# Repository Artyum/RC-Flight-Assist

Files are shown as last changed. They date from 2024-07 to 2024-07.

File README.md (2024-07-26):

# RC Flight Assist (RCFA) Telemetry System

RCFA is a telemetry system for RC pilots, designed specifically for outdoor pattern flying, such as F3A or F3M classes. The system provides better control over the airplane during acrobatics by implementing a radio telemetry mechanism that accurately indicates the position within the flight area. With RCFA, pilots can maintain the proper position in the sky, resulting in better handling and improved skills. The system was tested in collaboration with the top Polish F3A pilot of 2015.

#### How Does It Work?

The RCFA system comprises two separate electronic devices: the Transmitter and the Receiver. The primary role of the Transmitter is to get the 3D or 2D position from GPS and altimeter sensors and send the data to the pilot’s Receiver. The Receiver converts the signal into sound patterns, which the pilot can hear through the built-in speaker or headphones to receive telemetry information.

The basic usage of the RCFA involves defining two points on the ground to determine the flight area. The first point (P1) is the pilot’s position, where the airplane will be controlled from. The second point (P2) is the direction to the flight line where the airplane shall be controlled. These points can be set by walking with the RCFA to the desired positions on the airfield or by writing the coordinates in the configuration file (rcfa.ini). The optimal distance between P1 and P2 depends on GPS signal strength and usually does not need to be more than 20m.

#### Setting Up the Flight Area

Once points P1 and P2 are set within the Transmitter, the RCFA system automatically calculates the remaining flight area coordinates based on preset options: the ideal Flight Line (marked with points A, B, and C), the Green Zone (green color), and the Flight Area (blue color). The pilot’s job is to keep the airplane between the green rectangles.

During a flight, the RCFA Receiver generates tones that change according to the airplane’s distance from the Green Zone. This allows the pilot to react quickly and steer the airplane to the desired position in the sky. The pilot will know exactly how far the airplane is from the flight line, and whether it is ahead or behind the Green Zone, too high, or too far to the left or right side of the Flight Area.

#### Post-Flight Scoring

When the flight is over, the system calculates a score based on the time spent in the zone and overall flight time. This score is automatically stored in a KML file. The logger file can be opened instantly in Google Earth (Windows or Linux) to examine the flight and check the scoring.

#### Additional Features of the RCFA

**GPS Logger**: The system is highly customizable. Users can change various parameters such as the distance from the pilot to the flight line, area angle, flight plane width, and more (nearly 30 options). It has an integrated MicroSD slot for a memory card, which is used to store and read area parameters and to write position data as a high-accuracy GPS Logger. The system implements unique filter algorithms, ensuring high accuracy in the GPS data stream and altitude measurements. The RCFA also allows the use of a barometer for even more accurate altitude measurement. The Logger writes data directly in KML format, which can be instantly opened in Google Earth.

**Real-Time Tracking**: The RCFA can stream data to the Receiver about current 3D coordinates through the RX/TX interface (USB2TTL). The data stream (longitude, latitude, and altitude) can be read and visualized on a PC in real-time. Depending on barometer availability, the altitude data can be taken from GPS or barometer. Users can choose either absolute (mean sea level) or relative (to the pilot’s position) altitude readings.

**Variometer**: The RCFA includes a variometer feature, which can be used in gliders and other types of RC airplanes. The variometer can use GPS data or a barometer to indicate altitude changes. The data is sent to the Receiver, allowing the pilot to control descending or ascending in real-time.

# Overview
https://www.youtube.com/watch?v=m0nCrscLPIs

#### RC Flight Assist - Real-time tracking demo
https://www.youtube.com/watch?v=_wvuzFEu3uk

## Full Features List

The list of configurable parameters:
* Distance in meters between the Pilot and the Flight Line
* Area angle in degrees
* Flight Area width
* Flight line width
* Flight Area boundary alarm (Out-Of-Area)
* Altitude alarm
* Set points P1 and P2 manually
* Automatic Flight Area lock
* Real-time tracking
* Automatic reference altitude
* Manual setting of reference altitude
* GPS sample rate in 'Reads Per Second'
* GPS Logger Automatic mode
* GPS Logger Manual mode (free flight)
* Logger speed frequency
* Four different modes of Floor option
* "Low accuracy" information feature
* Configurable filtering algorithm for GPS, Altimeter, and Variometer
* Radio module switch
* Altimeter switch
* Variometer mode
* (Variometer) Minimum vertical speed ratio
* (Variometer) Maximum vertical speed ratio
* Time zone relative to UTC
* Initial sound volume in the Receiver
* Event log

### GPS Logger

RC Flight Assist can be used as a GPS Logger. The data is stored on a Micro SD card in KML format, which can be opened directly in Google Earth. The flight path is visualized as a line in 3D space as an animated track. The logger is controlled by several options:

1. **Stream Speed Frequency**: The coordinates can be saved every 0.5 to 60 seconds.
2. **GPS Data Acquiring Speed**: The data can be acquired 1, 5, or 10 times per second.
3. **Reference Altitude**: You can manually set the accurate reference altitude to ensure the plot is at the exact height. The altitude measurement relies on the high-accuracy barometer sensor MPL3115A2. If the barometer is not used, the altitude data is acquired from GPS.

The Logger can work in two modes:

**Automatic Mode**: Designed for acrobatic flights, so the pilot does not have to remember to enable or disable the Logger before each flight. The logger will start when the airplane flies into the flight zone and stop when leaving it.

**Manual Mode**: Along with the attached barometer, this makes RCFA a high-quality GPS Logger. In this mode, the Logger must be enabled and disabled manually by pressing the relevant buttons on the transmitter. To reduce energy drain, the radio module can be turned off.

### Real-time Tracking

The RC Flight Assist (RCFA) system is capable of sending position data to the Receiver in real-time. This data stream can be visualized on a PC directly in Google Earth. Currently, Google Earth has limited capabilities for displaying altitude in real-time mode. However, several third-party applications, such as GooPs (goopstechnologies.com) or EarthBridge (mboffin.com/earthbridge), can work as extensions to Google Earth to enhance its real-time tracking capabilities.

### Technical Details

**Radio Frequency**: 433MHz, 868MHz, 915MHz  
**Frequency-Hopping Spread Spectrum (FHSS)**  
**Range**: 700+/-100m (tested in open air with copper wire antenna)  
**Input Voltage**: 7-12V (2S/3S LiPo)  
**GPS Compatibility**: Global Top (MT3318, MT3329, MT3339), u-Blox (M7, M8)

#### Receiver (RX)
* **Headphones**: 3.5mm jack port
* **Average Current**: 50mA
* **Size**: 51 x 38mm
* **Weight**: ~17g

#### Transmitter (TX)
* **MicroSD Card**: 256MB-32GB class 4 (FAT32)
* **Maximum Transmit Power**: 20dB (100mW)
* **Average Current**: 150mA
* **Size**: 52 x 40mm

### Variometer

The RCFA Telemetry System can function as a variometer, providing real-time altitude data sourced from the GPS module or barometer (if available). Barometric altitude readings generally offer higher quality, but certain GPS modules such as u-Blox M8 or M7 series can also provide excellent 3D positioning signals. This telemetry system enables pilots to control ascents and descents in real-time from the ground. Specific sound patterns emitted by the receiver indicate altitude changes.

#### Customization Options

The variometer mode is highly customizable:
- **Low Pass**: Defines the minimum altitude change considered as horizontal flight.
- **High Pass**: Sets the altitude change threshold that triggers sound gradation in the speaker.

This flexibility allows pilots to tailor the variometer's responsiveness to their specific flying needs and preferences.

## RC Flight Assist (RCFA) Kit Components

#### 1. Transmitter
- **Description**: The transmitter module of the RCFA system is responsible for sending the aircraft's position data to the receiver. It gathers data from the GPS and altimeter sensors, then transmits this information using a specified radio frequency.
- **Key Features**:
  - Frequency-hopping spread spectrum (FHSS) support
  - Compatible with multiple GPS modules
  - Configurable transmission power
 
RCFA_TX

#### 2. Receiver
- **Description**: The receiver module receives position data from the transmitter and converts it into audible signals for the pilot. It helps in maintaining the aircraft within the designated flight area by providing real-time feedback.
- **Key Features**:
  - Headphone jack for audio feedback
  - Real-time tracking capability
  - Configurable sound patterns for various flight conditions
 
RCFA_RX

#### 3. GPS
- **Description**: The GPS module provides the necessary positional data for the RCFA system. It can determine the 2D or 3D position of the aircraft and relay this information to the transmitter.
- **Key Features**:
  - High compatibility (Global Top MT3318, MT3329, MT3339, u-Blox M7, M8 series)
  - Supports logging of satellite data
  - Provides accurate altitude data with the option to use a barometer for enhanced accuracy

#### 4. UART USB
- **Description**: The UART USB interface is used for configuring the RCFA system and for data logging purposes. It allows for easy communication between the RCFA modules and a PC for setup and data transfer.
- **Key Features**:
  - Enables configuration of system parameters via `rcfa.ini`
  - Facilitates firmware updates and debugging
  - Supports real-time data visualization on a PC using compatible software like Google Earth

IMG_20160701_214035_HDR

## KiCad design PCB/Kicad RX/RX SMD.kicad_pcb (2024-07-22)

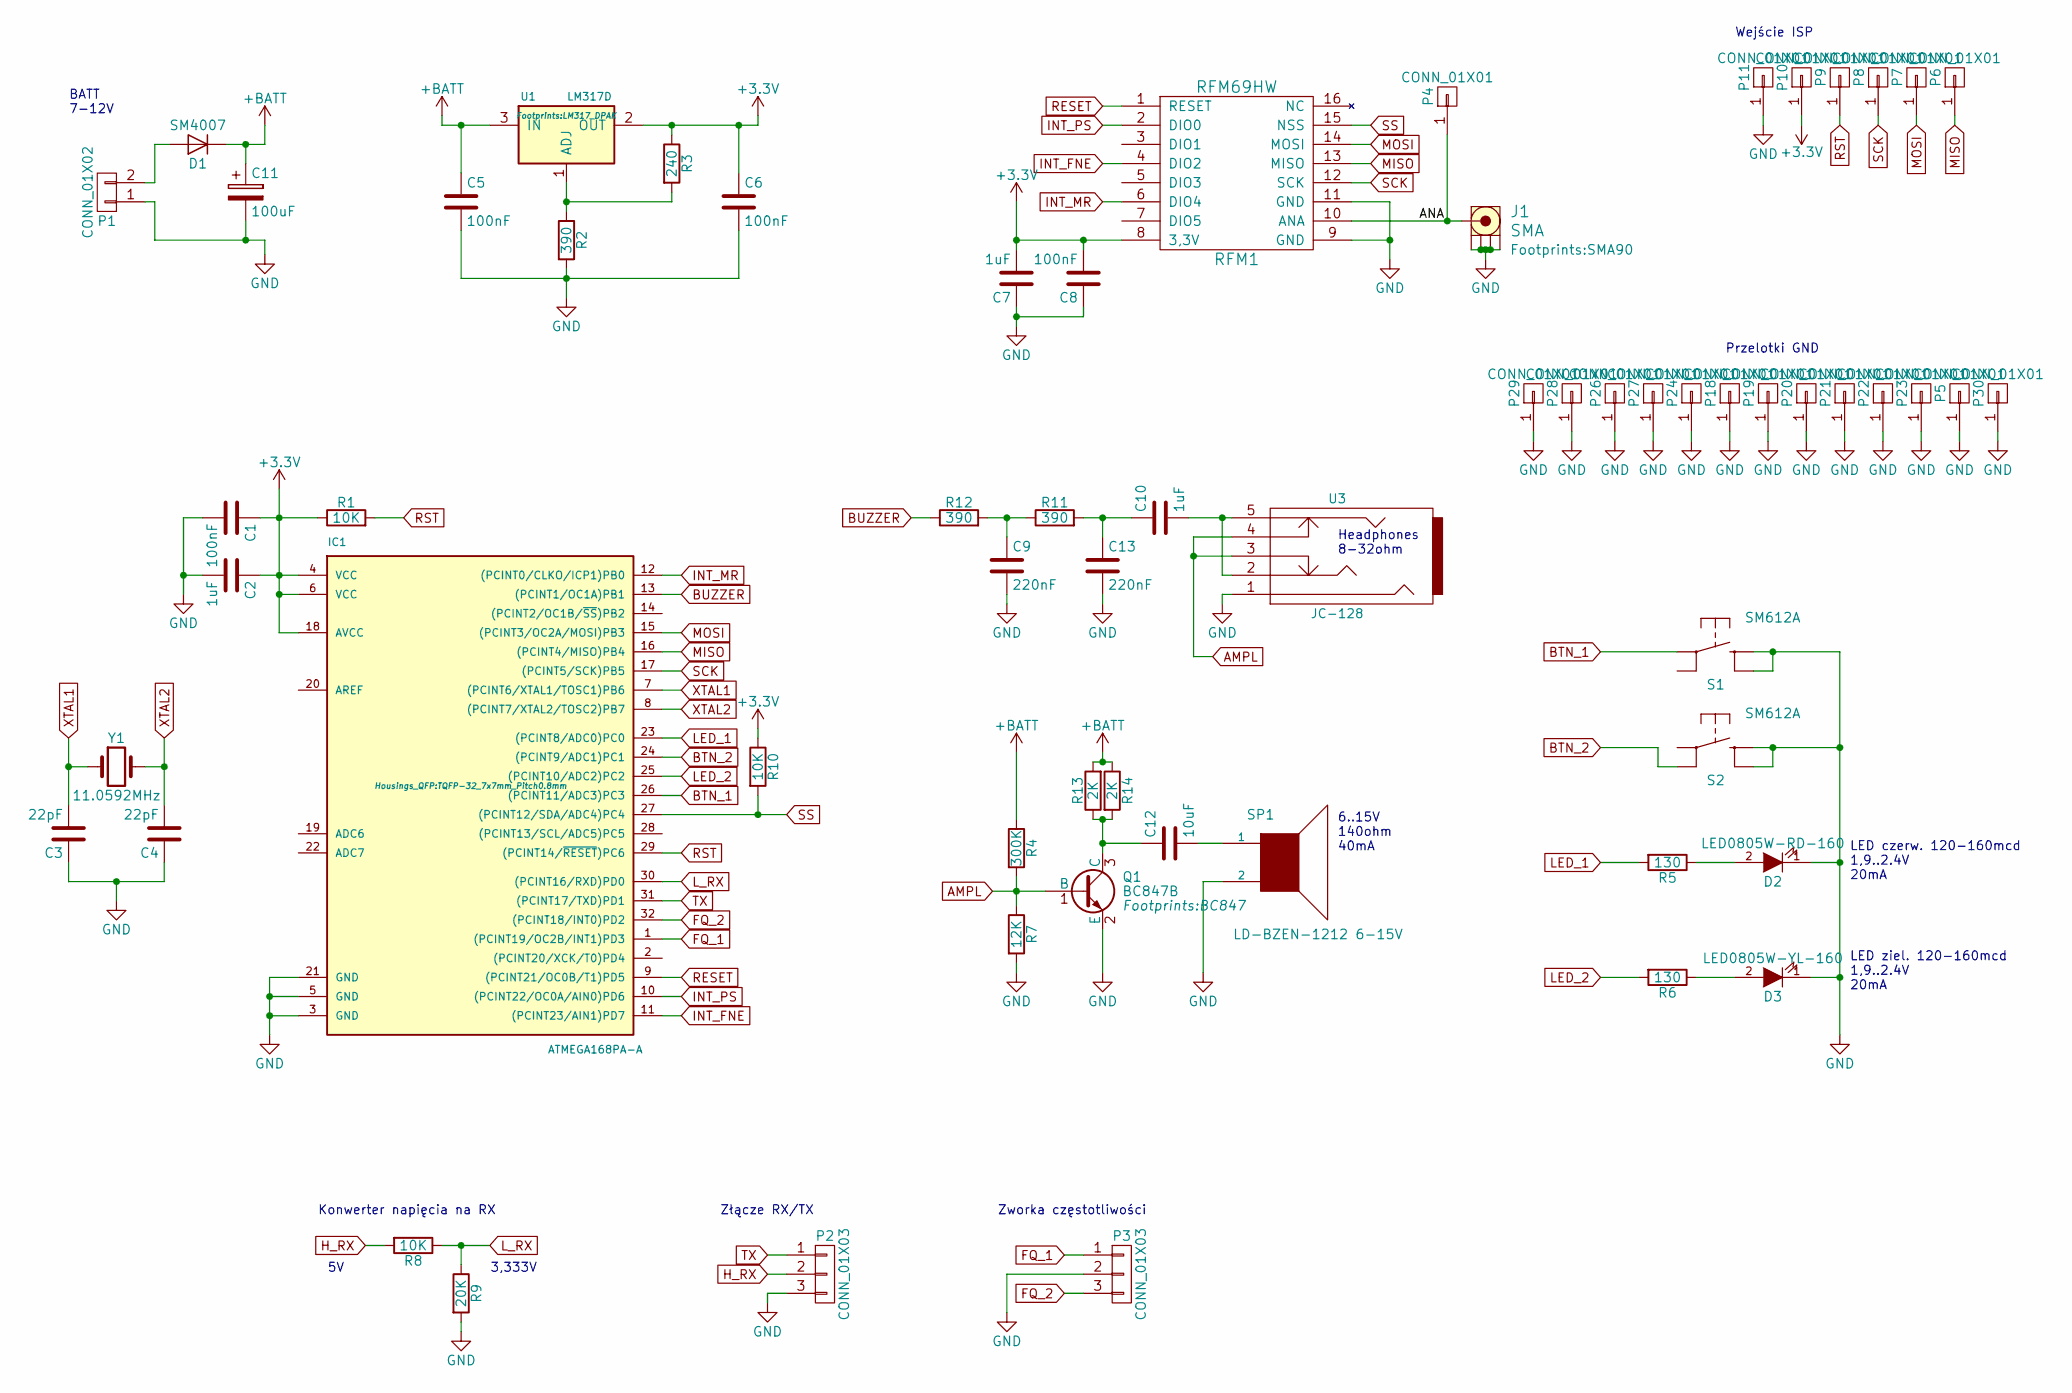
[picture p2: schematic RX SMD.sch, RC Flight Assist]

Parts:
C1, C5, C6, C8: 100nF; C_0805
C2, C7, C10: 1uF; C_0805
C3, C4: 22pF; C_0805
C9, C13: 220nF; C_0805
C11: 100uF; c_elec_6.3x5.3
C12: 10uF; C_0805
D1: SM4007; MELF_Standard
D2: LED0805W-RD-160; LED_0805
D3: LED0805W-YL-160; LED_0805
IC1: ATMEGA168PA-A; TQFP-32_7x7mm_Pitch0.8mm
J1: SMA; SMA90
P1: CONN_01X02; Pin_Header_Angled_1x02
P2, P3: CONN_01X03; Pin_Header_Angled_1x03
P4, P5, P6, P7, P8, P9, P10, P11, P18, P19, P20, P21, P22, P23, P24, P26, P27, P28, P29, P30: CONN_01X01; 1Pin
Q1: BC847B; BC847
R1, R8, R10: 10K; R_0805
R2, R11, R12: 390; R_0805
R3: 240; R_0805
R4: 300K; R_0805
R5, R6: 130; R_0805
R7: 12K; R_0805
R9: 20K; R_0805
R13, R14: 2K; R_0805
RFM1: RFM69HW; RFM69HW_SMD
S1, S2: SM612A; B3F_10XX
SP1: LD-BZEN-1212 6-15V; BUZZER_12x6.5
U1: LM317D; LM317_DPAK
U3: JC-128
Y1: 11.0592MHz; Crystal_HC49-U_Vertical

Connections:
+3V3: C1.1, C2.1, C6.1, C7.2, C8.2, IC1.4 (VCC), IC1.6 (VCC), IC1.18 (AVCC), P10.1, R1.1, R3.1, R10.1, RFM1.8 (3,3V), U1.2 (OUT)
+BATT: C5.1, C11.1, D1.1 (K), R4.1, R13.2, R14.1, U1.3 (IN)
/ANA: J1.1 (RF), P4.1, RFM1.10 (ANA)
AMPL: Q1.1 (B), R4.2, R7.1, U3.3, U3.4
BTN_1: IC1.26 ((PCINT11/ADC3)PC3), S1.3
BTN_2: IC1.24 ((PCINT9/ADC1)PC1), S2.4 (P1)
BUZZER: IC1.13 ((PCINT1/OC1A)PB1), R12.1
FQ_1: IC1.1 ((PCINT19/OC2B/INT1)PD3), P3.1
FQ_2: IC1.32 ((PCINT18/INT0)PD2), P3.3
GND: C1.2, C2.2, C3.1, C4.1, C5.2, C6.2, C7.1, C8.1, C9.2, C11.2, C13.2, D2.1 (K), D3.1 (K), IC1.3 (GND), IC1.5 (GND), IC1.21 (GND), J1.2 (GND1), J1.3 (GND2), J1.4 (GND3), J1.5 (GND4), P1.1, P2.3, P3.2, P5.1, P11.1, P18.1, P19.1, P20.1, P21.1, P22.1, P23.1, P24.1, P26.1, P27.1, P28.1, P29.1, P30.1, Q1.2 (E), R2.2, R7.2, R9.2, RFM1.9 (GND), RFM1.11 (GND), S1.1 (S), S1.2 (S1), S2.1 (S), S2.2 (S1), SP1.2, U3.1
H_RX: P2.2, R8.2
INT_FNE: IC1.11 ((PCINT23/AIN1)PD7), RFM1.4 (DIO2)
INT_MR: IC1.12 ((PCINT0/CLKO/ICP1)PB0), RFM1.6 (DIO4)
INT_PS: IC1.10 ((PCINT22/OC0A/AIN0)PD6), RFM1.2 (DIO0)
LED_1: IC1.23 ((PCINT8/ADC0)PC0), R5.2
LED_2: IC1.25 ((PCINT10/ADC2)PC2), R6.2
L_RX: IC1.30 ((PCINT16/RXD)PD0), R8.1, R9.1
MISO: IC1.16 ((PCINT4/MISO)PB4), P6.1, RFM1.13 (MISO)
MOSI: IC1.15 ((PCINT3/OC2A/MOSI)PB3), P7.1, RFM1.14 (MOSI)
unnamed: C9.1, R11.1, R12.2
unnamed: C10.1, C13.1, R11.2
unnamed: C10.2, U3.2, U3.5
unnamed: C12.1, Q1.3 (C), R13.1, R14.2
unnamed: C12.2, SP1.1
unnamed: D1.2 (A), P1.2
unnamed: D2.2 (A), R5.1
unnamed: D3.2 (A), R6.1
unnamed: R2.1, R3.2, U1.1 (ADJ)
RESET: IC1.9 ((PCINT21/OC0B/T1)PD5), RFM1.1 (RESET)
RST: IC1.29 ((PCINT14/~RESET~)PC6), P9.1, R1.2
SCK: IC1.17 ((PCINT5/SCK)PB5), P8.1, RFM1.12 (SCK)
SS: IC1.27 ((PCINT12/SDA/ADC4)PC4), R10.2, RFM1.15 (NSS)
TX: IC1.31 ((PCINT17/TXD)PD1), P2.1
XTAL1: C3.2, IC1.7 ((PCINT6/XTAL1/TOSC1)PB6), Y1.1
XTAL2: C4.2, IC1.8 ((PCINT7/XTAL2/TOSC2)PB7), Y1.2

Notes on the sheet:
LED czerw. 120-160mcd 1,9..2.4V 20mA
LED ziel. 120-160mcd 1,9..2.4V 20mA
Złącze RX/TX
Zworka częstotliwości
Konwerter napięcia na RX
BATT 7-12V
6..15V 140ohm 40mA
Headphones 8-32ohm
Wejście ISP
3,333V
Przelotki GND

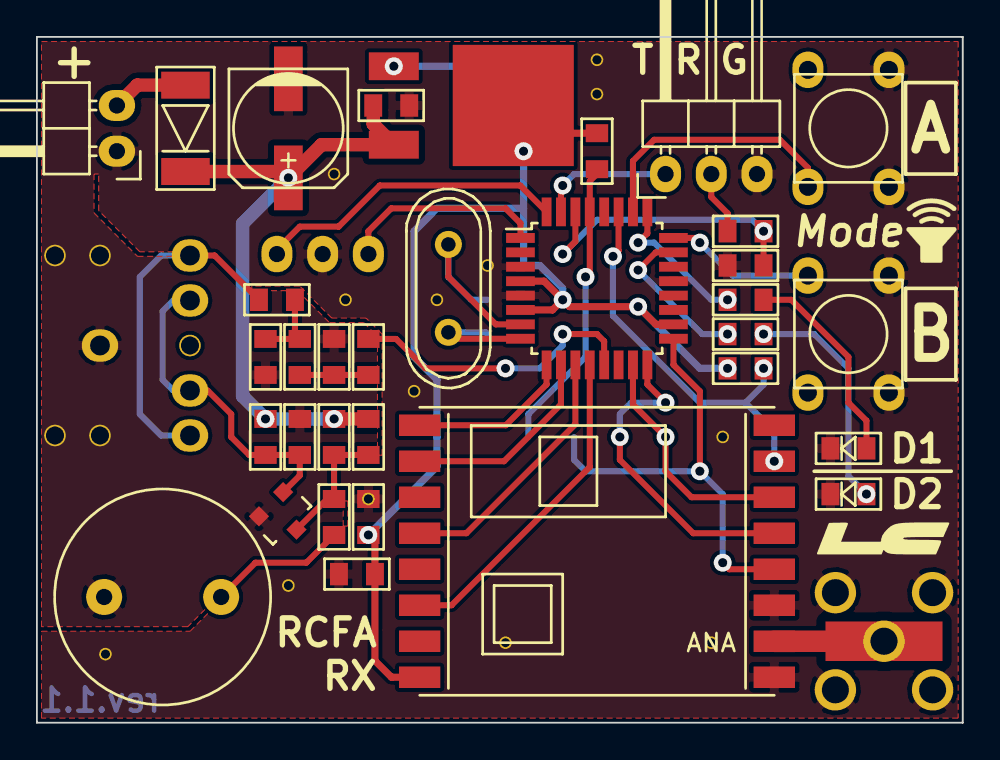
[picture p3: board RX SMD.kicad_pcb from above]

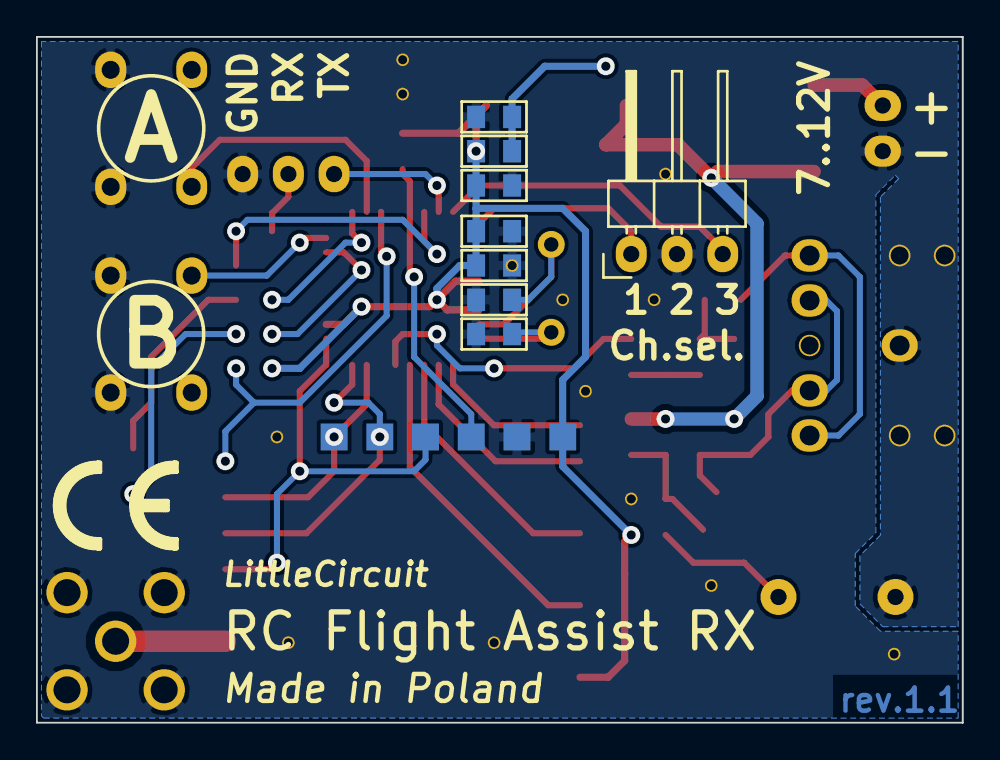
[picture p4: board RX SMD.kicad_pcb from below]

Board: 2 copper layers, 51.4 x 38.1 mm, 63 parts (8 on the bottom side), 35 nets.

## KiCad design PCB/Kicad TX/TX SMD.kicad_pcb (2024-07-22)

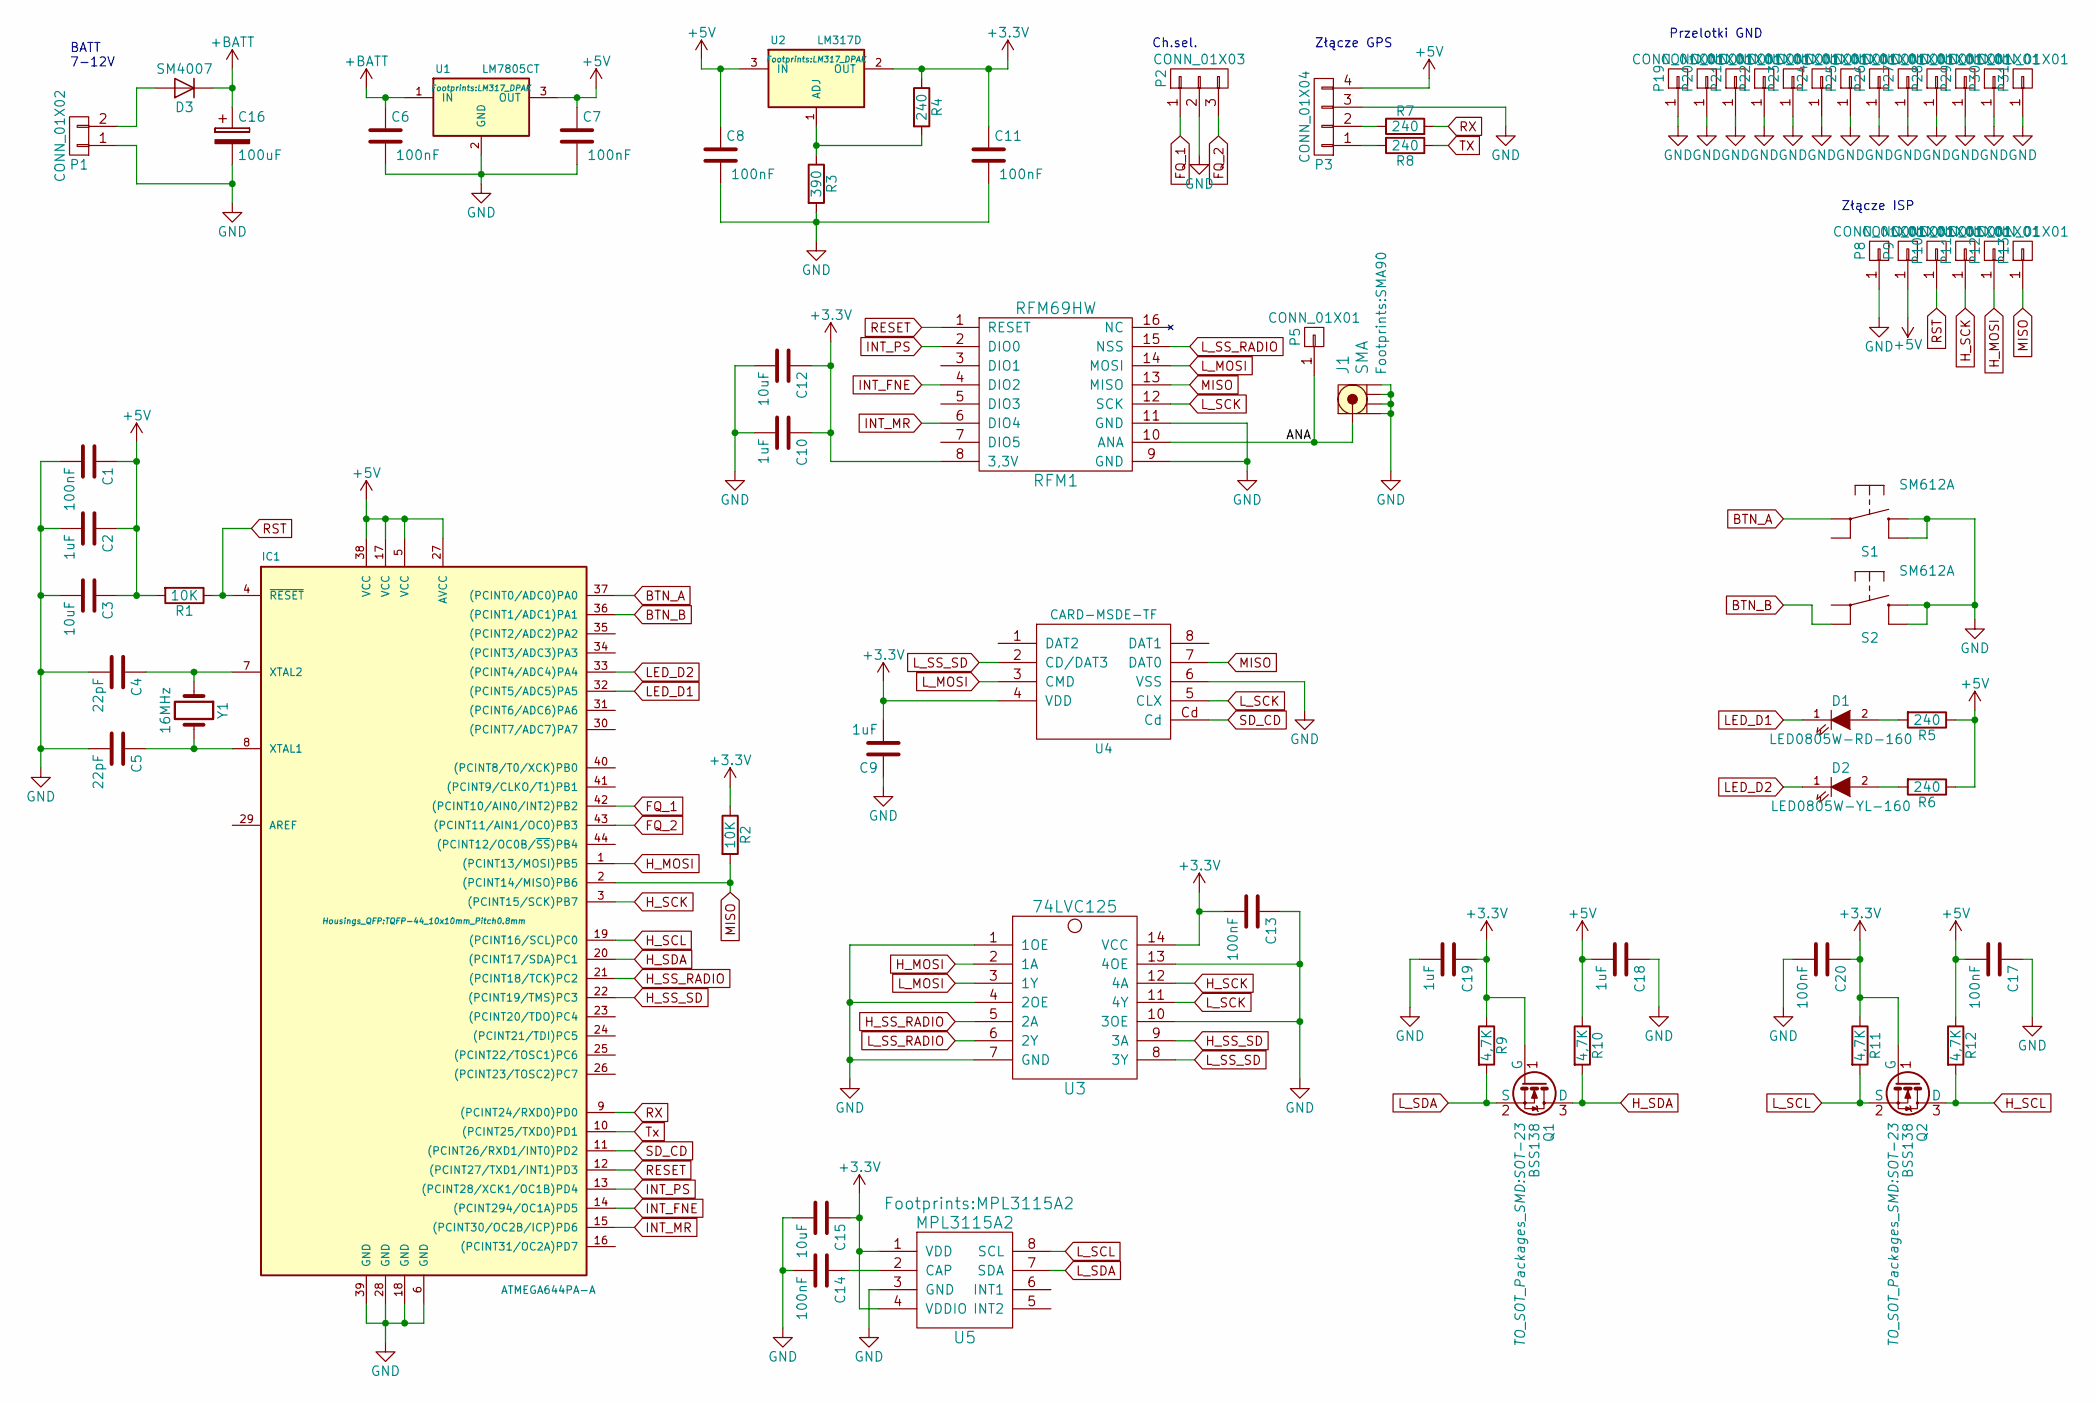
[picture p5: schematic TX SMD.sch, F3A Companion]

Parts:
C1, C6, C7, C8, C11, C13, C14, C17, C20: 100nF; C_0805
C2, C9, C10, C18, C19: 1uF; C_0805
C3, C12, C15: 10uF; C_0805
C4, C5: 22pF; C_0805
C16: 100uF; c_elec_6.3x5.3
D1: LED0805W-RD-160; LED_0805
D2: LED0805W-YL-160; LED_0805
D3: SM4007; MELF_Standard
IC1: ATMEGA644PA-A; TQFP-44_10x10mm_Pitch0.8mm
J1: SMA; SMA90
P1: CONN_01X02; Pin_Header_Angled_1x02
P2: CONN_01X03; Pin_Header_Angled_1x03
P3: CONN_01X04; Pin_Header_Angled_1x04
P5, P8, P9, P10, P11, P12, P13, P19, P20, P21, P22, P23, P24, P25, P26, P27, P28, P29, P30, P31: CONN_01X01; 1Pin
Q1, Q2: BSS138; SOT-23
R1, R2: 10K; R_0805
R3: 390; R_0805
R4, R5, R6, R7, R8: 240; R_0805
R9, R10, R11, R12: 4,7K; R_0805
RFM1: RFM69HW; RFM69HW_SMD
S1, S2: SM612A; B3F_10XX
U1: LM7805CT; LM317_DPAK
U2: LM317D; LM317_DPAK
U3: 74LVC125; SOIC-14_N
U4: CARD-MSDE-TF; Micro_SD_msde-tf
U5: MPL3115A2
Y1: 16MHz; Crystal_HC49-U_Vertical

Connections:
+3V3: C9.2, C10.1, C11.1, C12.1, C13.2, C15.1, C19.1, C20.1, Q1.1 (G), Q2.1 (G), R2.1, R4.1, R9.1, R11.1, RFM1.8 (3,3V), U2.2 (OUT), U3.14 (VCC), U4.4 (VDD), U5.1 (VDD), U5.4 (VDDIO)
+5V: C1.1, C2.1, C3.1, C7.1, C8.1, C17.2, C18.2, IC1.5 (VCC), IC1.17 (VCC), IC1.27 (AVCC), IC1.38 (VCC), P3.4, P9.1, R1.2, R5.1, R6.1, R10.1, R12.1, U1.3 (OUT), U2.3 (IN)
+BATT: C6.1, C16.1, D3.1 (K), U1.1 (IN)
/ANA: J1.1 (RF), P5.1, RFM1.10 (ANA)
BTN_A: IC1.37 ((PCINT0/ADC0)PA0), S1.3
BTN_B: IC1.36 ((PCINT1/ADC1)PA1), S2.4 (P1)
FQ_1: IC1.42 ((PCINT10/AIN0/INT2)PB2), P2.1
FQ_2: IC1.43 ((PCINT11/AIN1/OC0)PB3), P2.3
GND: C1.2, C2.2, C3.2, C4.2, C5.2, C6.2, C7.2, C8.2, C9.1, C10.2, C11.2, C12.2, C13.1, C14.2, C15.2, C16.2, C17.1, C18.1, C19.2, C20.2, IC1.6 (GND), IC1.18 (GND), IC1.28 (GND), IC1.39 (GND), J1.2 (GND1), J1.3 (GND2), J1.4 (GND3), J1.5 (GND4), P1.1, P2.2, P3.3, P8.1, P19.1, P20.1, P21.1, P22.1, P23.1, P24.1, P25.1, P26.1, P27.1, P28.1, P29.1, P30.1, P31.1, R3.2, RFM1.9 (GND), RFM1.11 (GND), S1.1 (S), S1.2 (S1), S2.1 (S), S2.2 (S1), U1.2 (GND), U3.1 (1OE), U3.4 (2OE), U3.7 (GND), U3.10 (3OE), U3.13 (4OE), U4.6 (VSS), U5.3 (GND)
H_MOSI: IC1.1 ((PCINT13/MOSI)PB5), P12.1, U3.2 (1A)
H_SCK: IC1.3 ((PCINT15/SCK)PB7), P11.1, U3.12 (4A)
H_SCL: IC1.19 ((PCINT16/SCL)PC0), Q2.3 (D), R12.2
H_SDA: IC1.20 ((PCINT17/SDA)PC1), Q1.3 (D), R10.2
H_SS_RADIO: IC1.21 ((PCINT18/TCK)PC2), U3.5 (2A)
H_SS_SD: IC1.22 ((PCINT19/TMS)PC3), U3.9 (3A)
INT_FNE: IC1.14 ((PCINT294/OC1A)PD5), RFM1.4 (DIO2)
INT_MR: IC1.15 ((PCINT30/OC2B/ICP)PD6), RFM1.6 (DIO4)
INT_PS: IC1.13 ((PCINT28/XCK1/OC1B)PD4), RFM1.2 (DIO0)
LED_D1: D1.1 (K), IC1.32 ((PCINT5/ADC5)PA5)
LED_D2: D2.1 (K), IC1.33 ((PCINT4/ADC4)PA4)
L_MOSI: RFM1.14 (MOSI), U3.3 (1Y), U4.3 (CMD)
L_SCK: RFM1.12 (SCK), U3.11 (4Y), U4.5 (CLX)
L_SCL: Q2.2 (S), R11.2, U5.8 (SCL)
L_SDA: Q1.2 (S), R9.2, U5.7 (SDA)
L_SS_RADIO: RFM1.15 (NSS), U3.6 (2Y)
L_SS_SD: U3.8 (3Y), U4.2 (CD/DAT3)
MISO: IC1.2 ((PCINT14/MISO)PB6), P13.1, R2.2, RFM1.13 (MISO), U4.7 (DAT0)
unnamed: C4.1, IC1.7 (XTAL2), Y1.1
unnamed: C5.1, IC1.8 (XTAL1), Y1.2
unnamed: C14.1, U5.2 (CAP)
unnamed: D1.2 (A), R5.2
unnamed: D2.2 (A), R6.2
unnamed: D3.2 (A), P1.2
unnamed: P3.1, R8.2
unnamed: P3.2, R7.1
unnamed: R3.1, R4.2, U2.1 (ADJ)
RESET: IC1.12 ((PCINT27/TXD1/INT1)PD3), RFM1.1 (RESET)
RST: IC1.4 (~RESET), P10.1, R1.1
RX: IC1.9 ((PCINT24/RXD0)PD0), R7.2
SD_CD: IC1.11 ((PCINT26/RXD1/INT0)PD2), U4.Cd
TX: IC1.10 ((PCINT25/TXD0)PD1), R8.1

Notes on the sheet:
BATT 7-12V
Złącze GPS
Ch.sel.
Przelotki GND
Złącze ISP

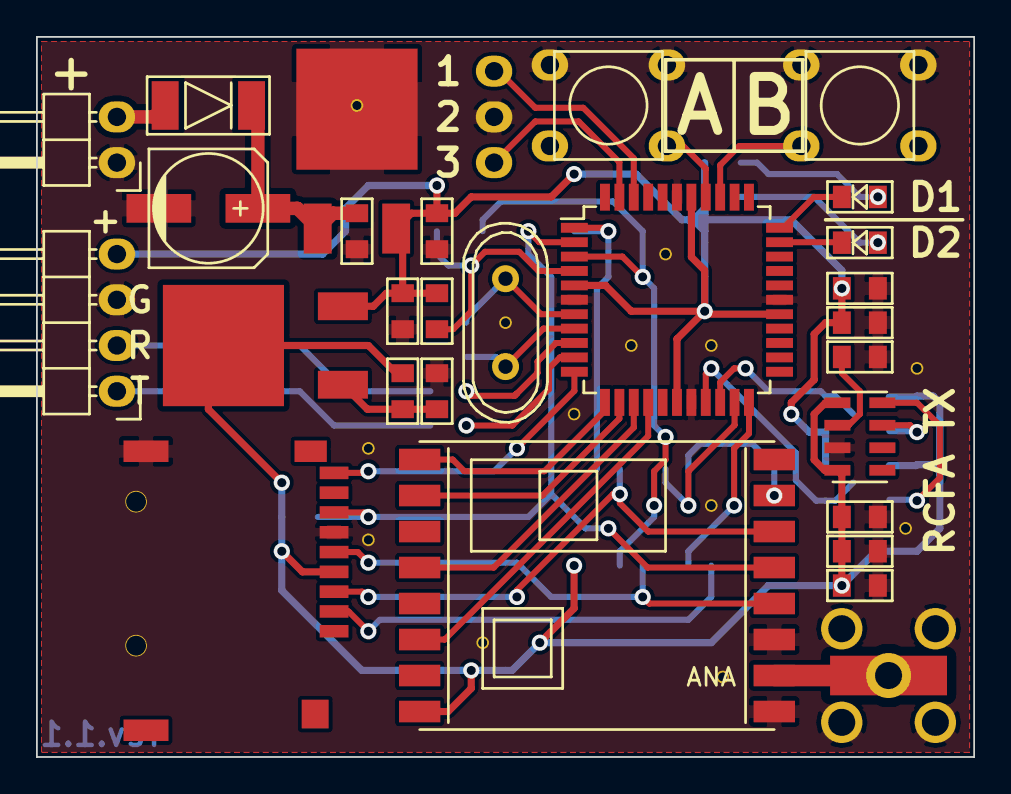
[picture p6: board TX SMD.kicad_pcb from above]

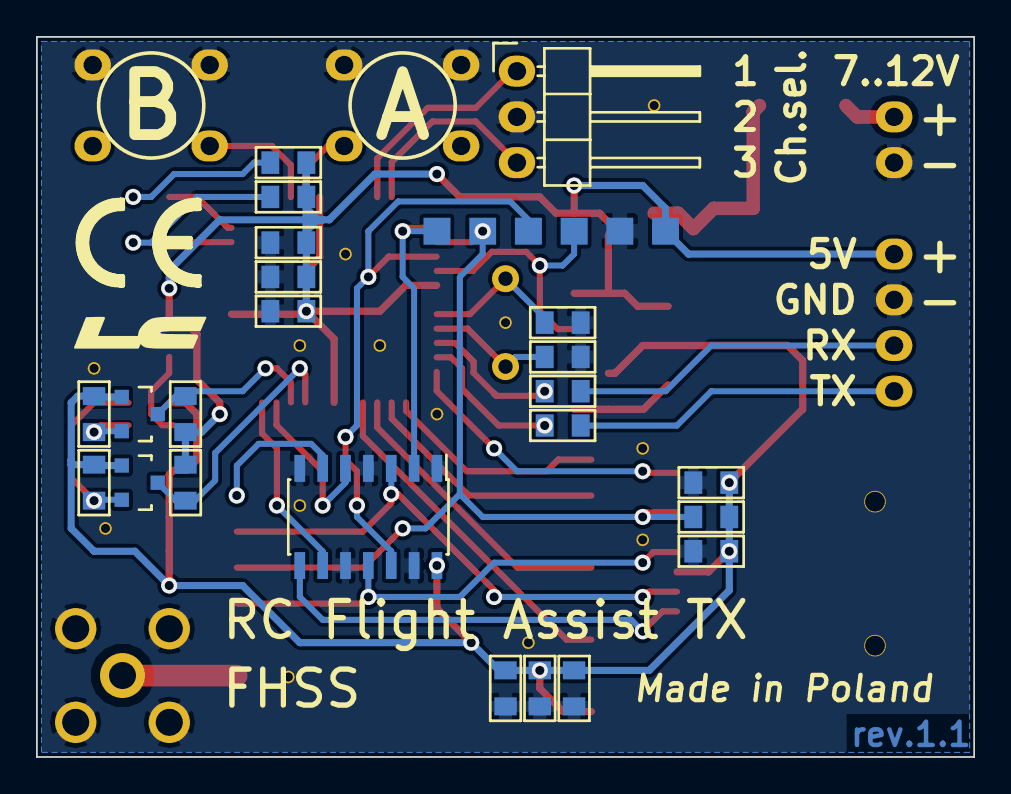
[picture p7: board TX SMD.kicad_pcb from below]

Board: 2 copper layers, 52.1 x 40.0 mm, 71 parts (23 on the bottom side), 41 nets.

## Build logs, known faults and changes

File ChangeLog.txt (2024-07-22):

v1.31
- Fixed parameter filter=1
- Added parameter hlowlimit in rcfa.ini

v1.2d
- Update for GPS command protocol. Compatible with uBlox series 5, 6, 7, M8 and GlobalTop MT3318, MT3329, MT3339.
- Optimized GPS data capture.
- Added logging of minimal and maximal number of active sattelites during flight on GPS Logger close. Available at log level 1.
- Added logging of every active sattelites count while the GPS Logger is running. Available at log level 4.
- Added log message "GPS module lost" in case of loss connection to the GPS module. Available at log level 4.
- Slighty increased transmission power of initial signals (configuration, reference position etc.).
- RCFA RX v1.2d1 - Slightly diversified pitch of tones "too close" (single tone higher pitch) and "too far" (double tone lower pitch)

v1.2c
- Fixed interference between devices working on different channels.
- Added delay (1-2 sec) after GPS fix recover to minimize the possibility of getting wrong position.
- Points P1 and P2 are now saved in the memory in situation when Flight Area is read from rcfa.ini and new Flight Area is set with A and B buttons.

v1.2b
- Fixed problem with reading data from memory, which in some circumstances, cause the device to reboot.
- Fixed memory reset function (test=2).

v1.2a
- The sound "Invalid GPS fix" will be played only during aerobatic flight (when the Flight Area is locked).
- Fixed corrupted kml output.
- Fixed saving wrong P1 and P2 coordinates after Area Lock.
- The "test" parameter in rcfa.ini behaviour upgrade. It is now possible to quickly check the Flight Area specified by parameters p1lat, p1lon, p2lat, p2lon.
  test=0 - Normal system operation
  test=1 - Firmware test enabled. If points p1 and p2 are set in rcfa.ini the system will create a kml file regarding given coordinates and other options (dist, angle, refalt etc)
           If points p1 and p2 are not set, the system will create a test kml file with Flight Area on Mount Everest
  test=2 - Reset points P1 and P2 in internal system memory.
- Slower LED initialization status blinking.
- More debug messages during RX initialization - available through UART.
- Fixed RX red LED status when txpos=0.

v1.2
- FHSS implemented.
- In automatic mode, GPS Logger won't stop/start if airplane crosses far end of Flight Area, prevents creating of a new kml file.
- "No connection" sound disabled (instead there is silence).

v1.1c
- Improved SD I/O - fixed problem with corrupted kml files.
- Added test=2 to reset P1 and P2 in internal memory.
- Improved Flight Area saving function.
- Improved firmware check function.

v1.1
Initial firmware release.

---------------------------------------------------------------------------------

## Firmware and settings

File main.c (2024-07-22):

/*
 * This file is part of RC Flight Assist (RCFA).
 *
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
 * Created for F3A pattern flying training
 * Developed in 2014/2015
 */

#include <avr/io.h>
#include "config.h"
#include "UART/uart.h"

#if PCB_REVISION==0
#include "CPU/cpu_1.0.h"
#elif PCB_REVISION==1
#include "CPU/cpu_1.1.h"
#endif

#if RADIO_MODE==0
#include "RCFA/rcfa_rx.h"
#else
#include "RCFA/rcfa_tx.h"
#endif

int main(void) {
	cpu_init();

	//Put firmware version to screen
	uart_init(UBRR_38400);
	uart_puts(FIRMWARE_VER); uart_nl();

	//Delay for peripheral hardware initialization
	delay_ms(100);

#if RADIO_MODE==0

	//Receiver
	rx_loop();

#else

	//Transmitter
	uart_disable();
	tx_loop();

#endif
}

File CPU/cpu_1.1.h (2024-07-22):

#ifndef _CPU_H_
#define _CPU_H_

#include "../config.h"
#include <avr/io.h>
#include "../RADIO/radio.h"

#if PCB_REVISION==1

#if CPU==0

//BUTTON
#define BTN1_DDR		DDRC
#define BTN1_PORT		PORTC
#define BTN1_PINPORT	PINC
#define BTN1_PIN		PC3
#define BTN2_DDR		DDRC
#define BTN2_PORT		PORTC
#define BTN2_PINPORT	PINC
#define BTN2_PIN		PC1

//BUZZER
#define BUZZER_DDR		DDRB
#define BUZZER_PORT		PORTB
#define BUZZER_PIN		PB1

//LED
#define LED1_DDR		DDRC
#define LED1_PORT		PORTC
#define LED1_PIN		PC0
#define LED2_DDR		DDRC
#define LED2_PORT		PORTC
#define LED2_PIN		PC2

//Radio interrupt
#define INT_DDR			DDRD
#define INT_PORT		PORTD
#define INT_PINPORT		PIND
#define INT_FNE_PIN		PD7
#define INT_CRC_PIN		PD6
#define INT_FIFO_NOT_EMPTY	(INT_PINPORT & (1<<INT_FNE_PIN))
#define INT_CRCOK			(INT_PINPORT & (1<<INT_CRC_PIN))

//Radio frequency switch
#define FQ_DDR			DDRD
#define FQ_PORT			PORTD
#define FQ_PINPORT		PIND
#define FQ_PIN_1		PD3
#define FQ_PIN_2		PD2

//SPI
#define SPI_DDR			DDRB
#define SPI_PORT		PORTB
//#define SPI_SS_PORT		PORTB
//#define SPI_SS			PB2
#define SPI_SS_ORG		PB2
#define SPI_MOSI		PB3
#define SPI_MISO		PB4
#define SPI_SCK			PB5

#define SPI_SS_DDR		DDRC
#define SPI_SS_PORT		PORTC
#define SPI_SS			PC4

#define TIMER_VECT		TIMER0_COMPA_vect

#define LED1_ON			BIT_HIGH(LED1_PORT,LED1_PIN)
#define LED1_OFF		BIT_LOW(LED1_PORT,LED1_PIN)

#define LED2_ON			BIT_HIGH(LED2_PORT,LED2_PIN)
#define LED2_OFF		BIT_LOW(LED2_PORT,LED2_PIN)

#elif CPU==1

//Button
#define BTN1_DDR		DDRA
#define BTN1_PORT		PORTA
#define BTN1_PINPORT	PINA
#define BTN1_PIN		PA0

#define BTN2_DDR		DDRA
#define BTN2_PORT		PORTA
#define BTN2_PINPORT	PINA
#define BTN2_PIN		PA1

//LED
#define LED1_DDR		DDRA
#define LED1_PORT		PORTA
#define LED1_PIN		PA4

#define LED2_DDR		DDRA
#define LED2_PORT		PORTA
#define LED2_PIN		PA5

//Radio interrupt
#define INT_DDR			DDRD
#define INT_PORT		PORTD
#define INT_PINPORT		PIND
#define INT_PS_PIN		PD4
#define INT_FNE_PIN		PD5
#define INT_MR_PIN		PD6
#define INT_PACKET_SENT		(INT_PINPORT & (1<<INT_PS_PIN))
#define INT_FIFO_NOT_EMPTY	(INT_PINPORT & (1<<INT_FNE_PIN))
#define INT_CRCOK			(INT_PINPORT & (1<<INT_CRC_PIN))

//SPI Radio
#define SPI_DDR			DDRB
#define SPI_PORT		PORTB
#define SPI_MOSI		PB5
#define SPI_MISO		PB6
#define SPI_SCK			PB7
#define SPI_SS_ORG		PB4

//SPI frequency for the radio
//#define RADIO_FCLK	SPCR = (1<<SPE)|(1<<MSTR)|(1<<SPR0)				/* F_CPU / 16 */
//#define RADIO_FCLK	SPCR = (1<<SPE)|(1<<MSTR)						/* F_CPU / 4 */

//SS
#define SPI_SS_DDR		DDRC
#define SPI_SS_PORT		PORTC
#define SPI_SS			PC2		/* SPI -> Radio */
#define SPI_SS_SD		PC3		/* SPI -> SD */

//Karta SD
#define SD_PORT			PORTD
#define SD_PIN			PIND
#define SD_CD			PD2		/* Card Detected */
//#define SD_WP			PB1		/* Write protected */

//Radio frequency switch
#define FQ_DDR			DDRB
#define FQ_PORT			PORTB
#define FQ_PINPORT		PINB
#define FQ_PIN_1		PB2
#define FQ_PIN_2		PB3

#define TIMER_VECT		TIMER0_COMPA_vect

#define SD_CS_LOW		SPI_SS_PORT &= ~(1<<SPI_SS_SD)		/* CS=low */
#define SD_CS_HIGH		SPI_SS_PORT |= (1<<SPI_SS_SD)		/* CS=high */
//#define SD_PWR_LOW	SD_PORT &= ~(1<<SD_PWR)
//#define SD_PWR_HIGH	SD_PORT |= (1<<SD_PWR)

//Card detected.   yes:true, no:false, default:true
#define SD_MMC_CD		(!(SD_PIN & (1<<SD_CD)))

//Write protected. yes:true, no:false, default:false
//#define SD_MMC_WP		(SD_PIN & (1<<SD_WP))
#define SD_MMC_WP		0

//SPI frequency for SD
//#define SD_FCLK_SLOW	SPCR = (1<<SPE)|(1<<MSTR)|(1<<SPR1)|(1<<SPR0)	/* F_CPU / 128 */
//#define SD_FCLK_SLOW	SPCR = (1<<SPE)|(1<<MSTR)|(1<<SPR1)				/* F_CPU / 64 */
//#define SD_FCLK_SLOW	SPCR = (1<<SPE)|(1<<MSTR)|(1<<SPR0)				/* F_CPU / 16 */

//#define SD_FCLK_FAST	SPCR = (1<<SPE)|(1<<MSTR)|(1<<SPR1)				/* F_CPU / 128 */
//#define SD_FCLK_FAST	SPCR = (1<<SPE)|(1<<MSTR)|(1<<SPR1)				/* F_CPU / 64 */
//#define SD_FCLK_FAST	SPCR = (1<<SPE)|(1<<MSTR)|(1<<SPR0)				/* F_CPU / 16 */
//#define SD_FCLK_FAST	SPCR = (1<<SPE)|(1<<MSTR)						/* F_CPU / 4 */

#define LED1_ON			BIT_LOW(LED1_PORT,LED1_PIN)
#define LED1_OFF		BIT_HIGH(LED1_PORT,LED1_PIN)

#define LED2_ON			BIT_LOW(LED2_PORT,LED2_PIN)
#define LED2_OFF		BIT_HIGH(LED2_PORT,LED2_PIN)

#endif

// ************************************************************************************************************* //
// Macros and definitions

#define BIT_LOW(PORT,PIN)		PORT &= ~(1<<PIN)
#define BIT_HIGH(PORT,PIN)		PORT |= (1<<PIN)
#define BIT_TOG(PORT,PIN)		PORT ^= (1<<PIN)
//Returns 1 if bit == 1; 0 if bit == 0
#define READ_BIT(PINPORT,PIN)	(PINPORT & (1<<PIN))

#define LED1_TOG		BIT_TOG(LED1_PORT,LED1_PIN)
#define LED2_TOG		BIT_TOG(LED2_PORT,LED2_PIN)

//The number of elements in the array
#define NUM_ELEMENTS(x)	(sizeof(x)/sizeof(x[0]))

extern volatile uint16_t t_led1;
extern volatile uint16_t t_led2;
extern uint8_t led1_status;
extern uint8_t led2_status;

void cpu_init(void);
void delay_ms(uint16_t time);

#endif
#endif /* _CPU_H_ */

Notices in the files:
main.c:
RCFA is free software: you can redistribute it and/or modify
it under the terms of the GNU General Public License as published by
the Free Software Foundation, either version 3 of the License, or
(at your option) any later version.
